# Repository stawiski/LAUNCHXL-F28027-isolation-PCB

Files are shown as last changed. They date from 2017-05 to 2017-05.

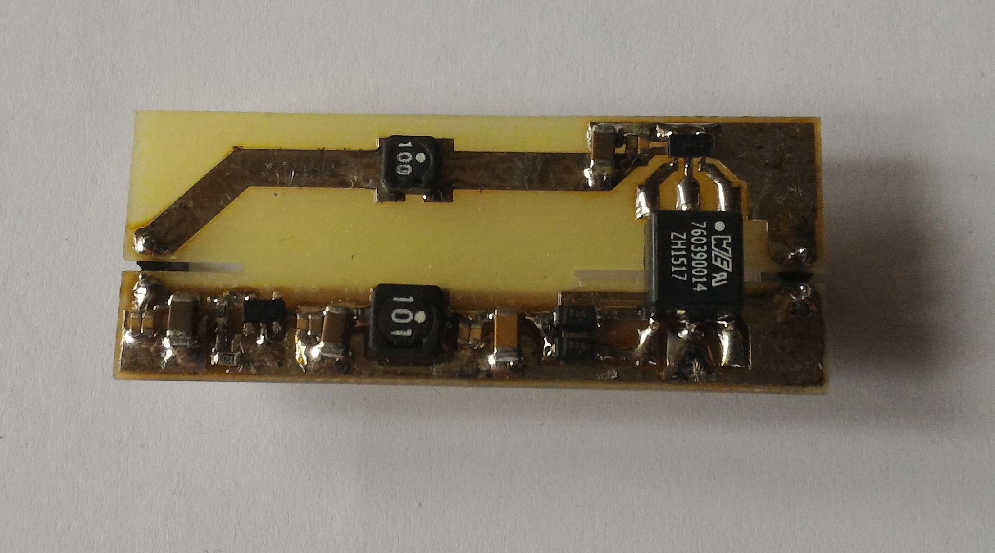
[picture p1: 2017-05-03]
photos/pcb_top.jpg

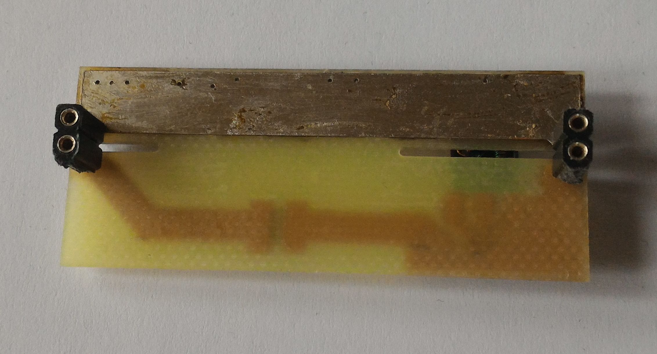
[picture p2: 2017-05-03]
photos/pcb_bottom.jpg

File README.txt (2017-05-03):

This is an isolated power supply PCB for Texas Instrument's C2000 Launchpad (LAUNCHXL-F28027) Kit.

C2000 Launchpad is equipped with two ISO72XX chips for isolated JTAG and UART.
To achieve isolation, the MCU has to be powered up on it's side.

As I needed the Launchpad for fast prototyping of other projects (having a PWM generator, gathering some ADC data etc.), I've came up with this little plug-in board.
It will power up the MCU on it's side from the available USB debugger/programmer voltage and provide full isolation.

I find it really handy as one avoids ground loops, which might be a source of noise or other problems in the circuit.

I've used this PCB to get a simple isolated PWM generator as well as isolated ADC measurements (check out my other repositories).
The isolation is limited by the Launchpad itself and I would certainly not go with it above 1kV potential difference (look at the small clearance in the Launchpad PCB).

The isolated power supply board only takes 3.3V from the Launchpad and provides isolated 3.3V, so 5V is not available anymore on the MCU side (the jumper must be disconnected!).
The maximum output current of this supply is limited mainly by the transformer and transformer driver chip and is around 150mA.
However, I would not go above 100mA load, just for precaution.

The PCB was designed in KiCad 2013-07-07.
It's not prepared for mass production.
I did it without soldermask/silkscreen/paste layers. Just hand-soldered myself.

Those layers are available in the project, though.
If you want to order that PCB using the gerbers, look out for the clearance of the connector's pads (P1 and P2).
I've made the pads really small compared to the drill size on purpose!
You might need to change those depending on your choice of PCB manufacturer and their DRC.

Stawiski

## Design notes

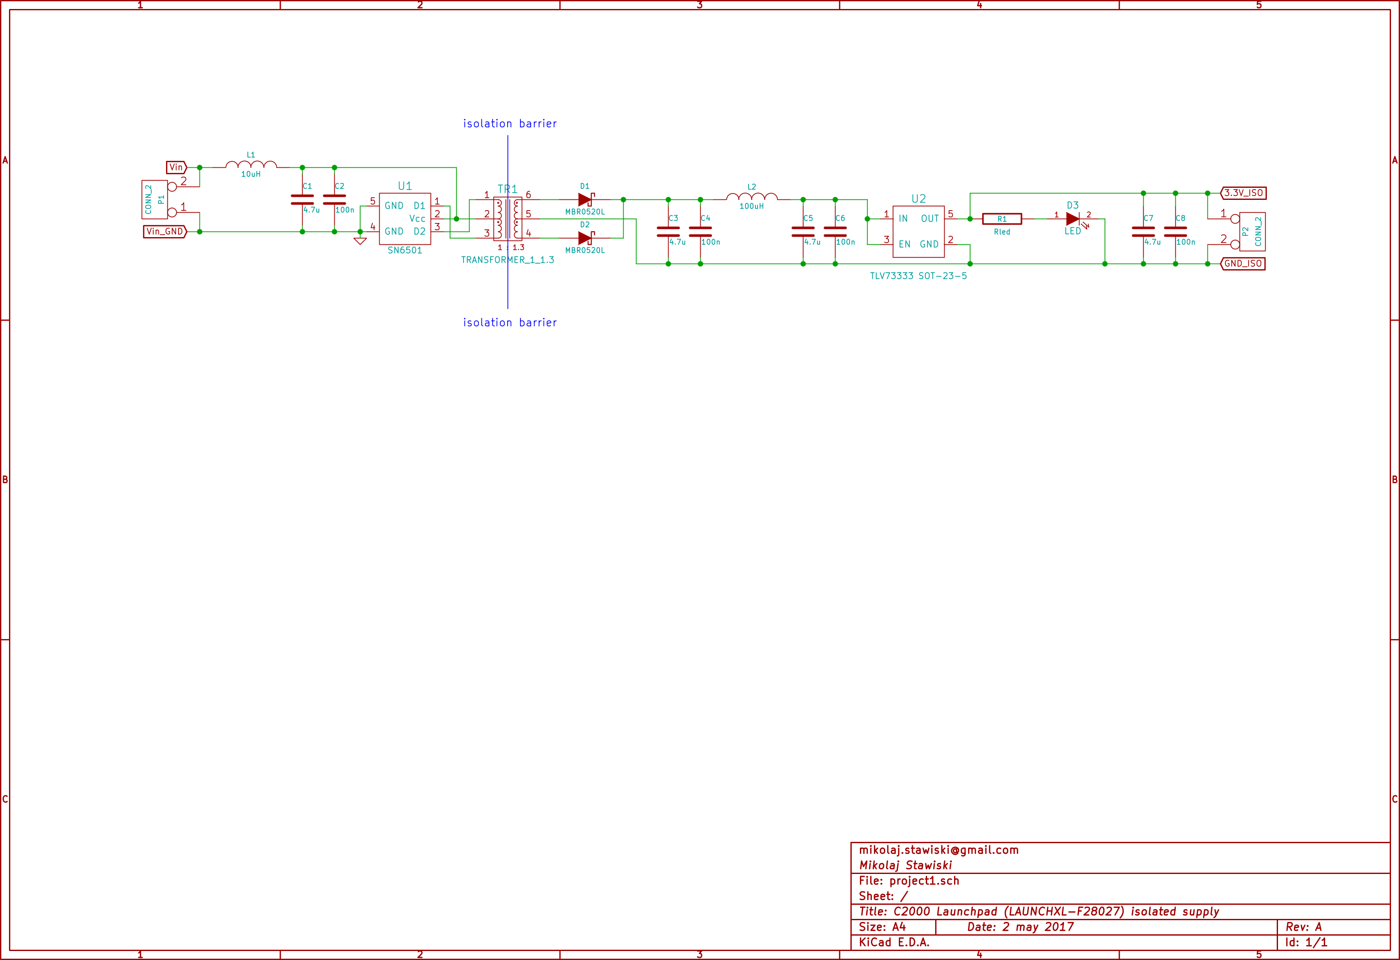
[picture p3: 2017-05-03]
kicad/exports/schematic.png

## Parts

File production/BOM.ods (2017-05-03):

ID | Type | Name | Value | Footprint | Additional info | Webpage | Count | Comment
R1 | SMD | Resistor | Rled | 0805 | optional |  | 1
C1 C3 C5 C7 | SMD | Capacitor | 4.7u | 1206 | 16V |  | 4
C2 C4 C6 C8 | SMD | Capacitor | 100n | 0805 | 16V |  | 4
D1 D2 | SMD | Diode | MBR0520L | SOD-123 |  | http://www.mouser.de/ProductDetail/ON-Semiconductor/MBR0520LT1G/ | 2 | Small Vfwd, fast recovery time, 300mA
D3 | SMD | LED | LED, Vfw < 3V, Ifw < 5mA | 0805 | optional |  | 1 | LED indicates power in the isolated side
L1 | SMD | Inductor | 10uH | VLCF5020 | VLCF4020 inductor series |  | 1 | VLCF4020 will also fit in VLCF5020 footprint
L2 | SMD | Inductor | 100uH | VLCF5020 | VLCF5020 inductor series |  | 1
TR1 | SMD | Transformer | TRANSFORMER_1_1.3 | transf_isol_wurth | Isolating transformer 1:1.3 turns ratio | http://www.mouser.de/ProductDetail/Wurth-Electronics/760390014/ | 1 | 760390014 for 2.5kV isolation, 750313638 for 5.0kV isolation. LaunchPad limit is around 1kV anyway.
U1 | SMD | Transformer driver | SN6501 | SOT-23-5 | Texas Instruments | http://www.mouser.de/ProductDetail/Texas-Instruments/SN6501DBVR/?qs=sGAEpiMZZMvkeWd5e1O6r9r5F%252blOC%252bIf | 1
U2 | SMD | LDO | TLV73333 | SOT-23-5 | Texas Instruments | http://www.mouser.de/ProductDetail/Texas-Instruments/TLV73333PDBVR/ | 1 | Low Vdrop regulator for greater efficiency
P1 P2 | THT | Goldpins | 2-pin 2.54mm pitch female | PIN_ARRAY_2X1 |  |  | 2

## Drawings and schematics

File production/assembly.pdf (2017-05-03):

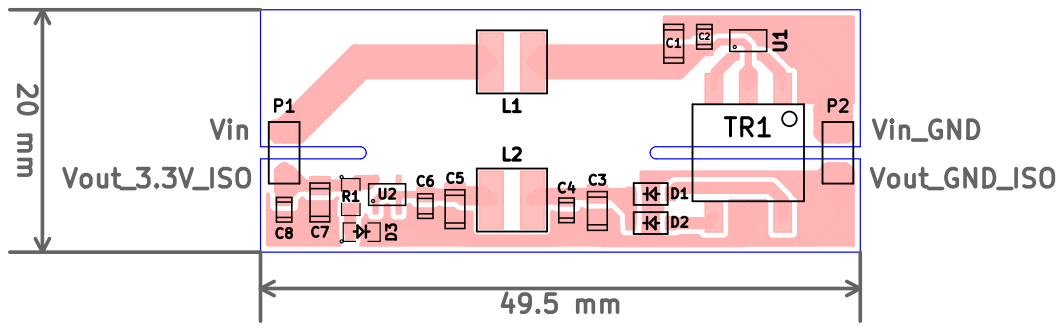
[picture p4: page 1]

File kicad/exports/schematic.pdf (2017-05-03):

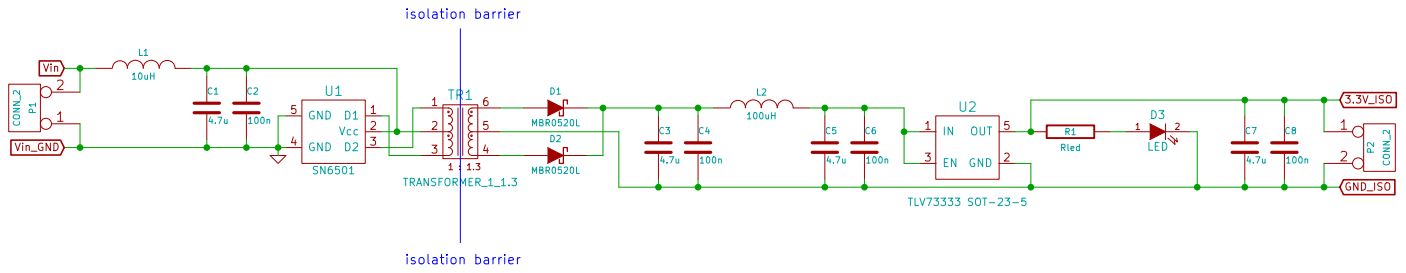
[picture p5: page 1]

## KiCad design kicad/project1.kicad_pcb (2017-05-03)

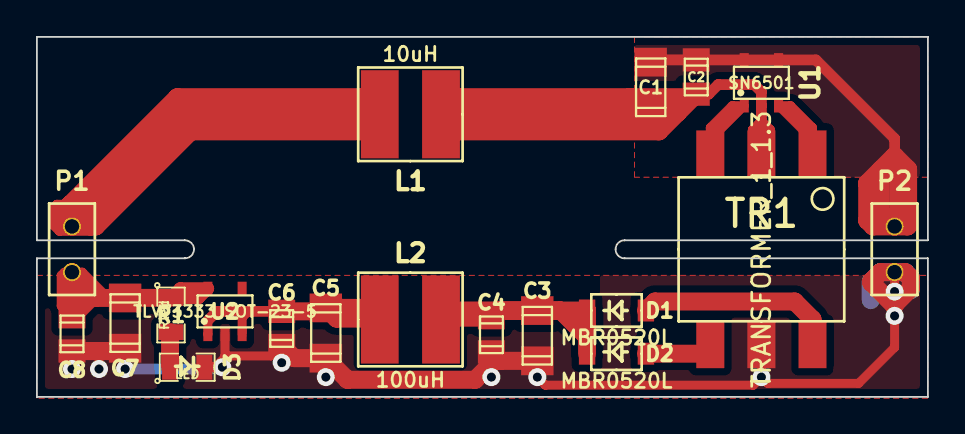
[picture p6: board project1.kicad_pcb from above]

Board: 2 copper layers, 49.5 x 20.0 mm, 19 parts (0 on the bottom side), 12 nets.

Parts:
C1, C3, C5, C7: 4.7u; c_1206
C2, C4, C6, C8: 100n; c_0805
D1, D2: MBR0520L; SOD-123
D3: LED; SM0805
L1: 10uH; VLCF5020
L2: 100uH; VLCF5020
P1, P2: CONN_2; PIN_ARRAY_2X1
R1: Rled; SM0805
TR1: TRANSFORMER_1_1.3; transf_isol_wurth
U1: SN6501; SOT23-5
U2: TLV73333 SOT-23-5; SOT23-5

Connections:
3.3V: L1.1, P1.2
3.3V isol: C7.1, C8.1, P1.1, R1.1, U2.5
GND: C1.2, C2.2, P2.2, U1.4, U1.5
GND_isol: C3.2, C4.2, C5.2, C6.2, C7.2, C8.2, D3.2, P2.1, TR1.5, U2.2
unnamed: C1.1, C2.1, L1.2, TR1.2, U1.2
unnamed: D3.1, R1.2
unnamed: TR1.1, U1.3
unnamed: TR1.3, U1.1
unnamed: C3.1, C4.1, D1.2, D2.2, L2.1
unnamed: D1.1, TR1.6
unnamed: D2.1, TR1.4
unnamed: C5.1, C6.1, L2.2, U2.1, U2.3

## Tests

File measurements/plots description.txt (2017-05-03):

Measurement parameters

Vin = 3.308V
Vrec (voltage after rectifying diodes) = 3.866V
Vout = 3.292V (load current = 50mA)

plot1 - Vrec voltage, AC coupled, probing between GND near transformer and after both shottky diodes
plot2 - drain voltages of SN6501 chip showing the switching, DC coupled
plot3 - output voltages of the transformer, before shottky diodes, DC coupled

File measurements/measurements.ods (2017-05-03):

Vin [V] | Vrec [V] | Vout [V] | R_load [Ohm] | I_load [mA]
3,308 | 4,254 | 3,299 | - | 0
3,889 | 5,03 | 3,3 | - | 0
2,521 | 3,644 | 3,3 | - | 0
2,749 | 3,092 | 3,013 | 65,75 | 45,83
2,926 | 3,333 | 3,247 | 65,75 | 49,38
2,981 | 3,407 | 3,293 | 65,75 | 50,08
3,797 | 4,53 | 3,292 | 65,75 | 50,07
4,175 | 5,038 | 3,292 | 65,75 | 50,07
